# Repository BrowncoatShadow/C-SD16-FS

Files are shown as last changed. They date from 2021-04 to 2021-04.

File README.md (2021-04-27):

# Chauvet Stage Designer 16 Foot Pedal USB Macro Pad

This is a simple project to create an adapter that turns a Chauvet Stage
Designer 16 foot pedal into a USB macro foot switch.

The foot pedal is a very simple device. It has four spring-loaded pedals over
a PCB with four momentary switches. The PCB connects to a standard male DB-9
D-SUB connector. It uses pin 5 as a common line for the switches, and pins
1-4 as the signal pins for the switches.

A [DB-9 "motherboard" connector](https://www.amazon.com/gp/product/B0067DB6RU)
can be used as a simple adapter, because it breaks out the DB-9 pins to a
standard 2x5 pin IDC header; which can be easily connected to a microcontroller.

This project uses the [Adafruit Feather M0 Express](https://www.adafruit.com/product/3403)
microcontroller because it has USB HID support, intigrated pullup resisters,
and a nice proto perf board area to mount a 2x5 socket for the DB-9 adapter.

## Pinout Diagram

```
  DB-9 Male          IDC Header
                        ┌─┐
┌───────────┐      ┌────┴─┴─ ──┐
│ 1 2 3 4 5 │ ───► │ 1 2 5 8 9 │
│  6 7 8 9  │      │ 3 6 4 7 X │
└───────────┘      └───────────┘

  Connection        DB-9   Pin
  ────────────────────────────
  Ground            5      GND
  P1 (FULL ON)      4      A1
  P2 (STAND BY)     3      A2
  P3 (PATTERN UP)   2      A3
  P4 (STEP UP)      1      A4
```

## References
* [Feather Specification](https://learn.adafruit.com/adafruit-feather/feather-specification)
* [Feather M0 Express Reference](https://learn.adafruit.com/adafruit-feather-m0-basic-proto/overview)
* [Feather M0 Express CAD Model](https://github.com/adafruit/Adafruit_CAD_Parts/blob/master/3403%20Feather%20M0%20Express/3403%20Feather%20M0%20Express.stl)
* [CircuitPython Getting Started Guide](https://learn.adafruit.com/welcome-to-circuitpython)
* [Adafruit HID Library Documentation](https://circuitpython.readthedocs.io/projects/hid/en/latest/)
* [circup](https://github.com/adafruit/circup)

## Attributions
* Enclosure design is based on Heartman's [OpenScad Parametric Box](https://www.thingiverse.com/thing:1264391) [CC BY-NC 3.0 License]

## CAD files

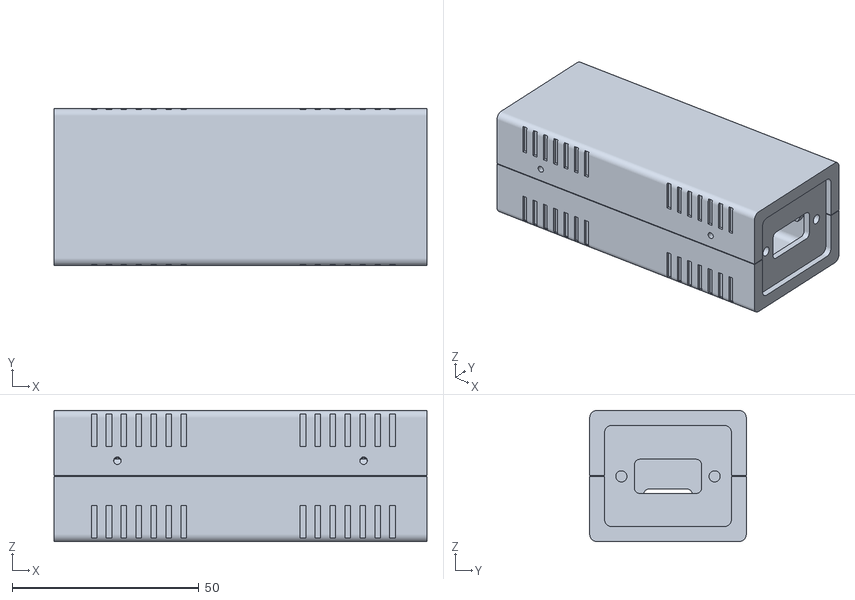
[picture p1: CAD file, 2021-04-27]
enclosure/stl/full.stl
100.0 x 42.0 x 35.2

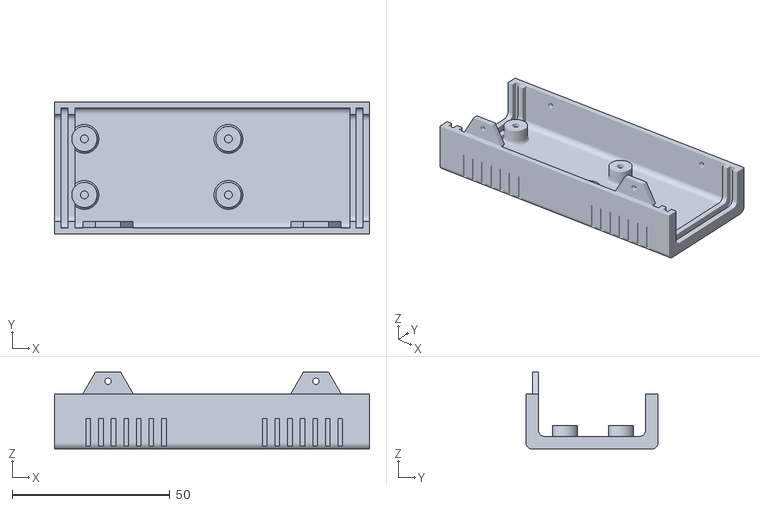
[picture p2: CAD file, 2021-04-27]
enclosure/stl/bottom_shell.stl
100.0 x 42.0 x 24.4

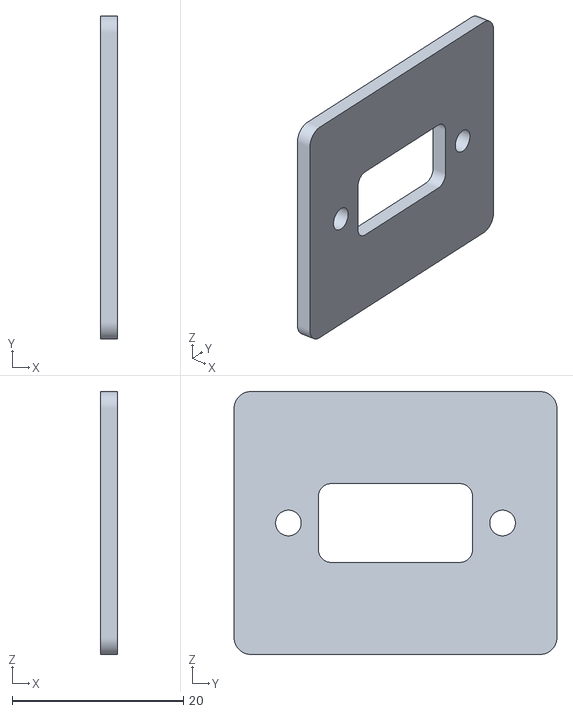
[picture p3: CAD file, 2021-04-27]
enclosure/stl/front_panel.stl
2.00 x 37.7 x 30.7

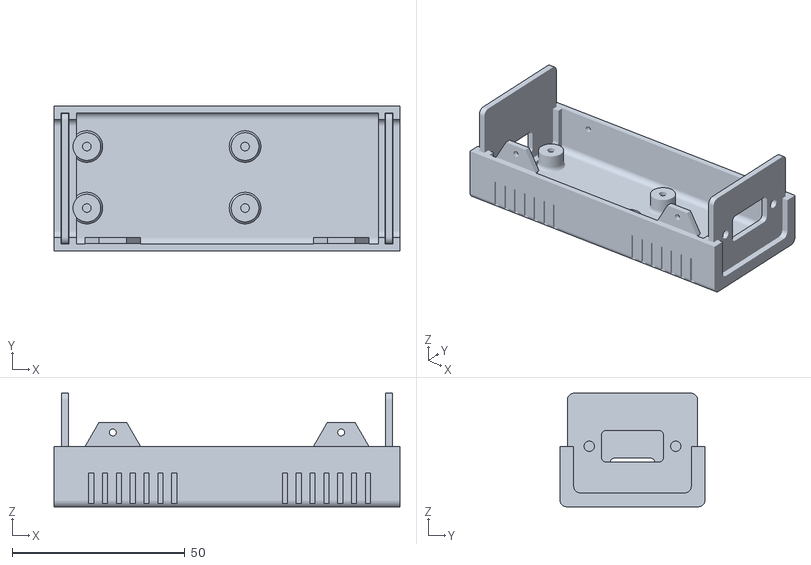
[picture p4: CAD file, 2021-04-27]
enclosure/stl/topless.stl
100.0 x 42.0 x 32.9

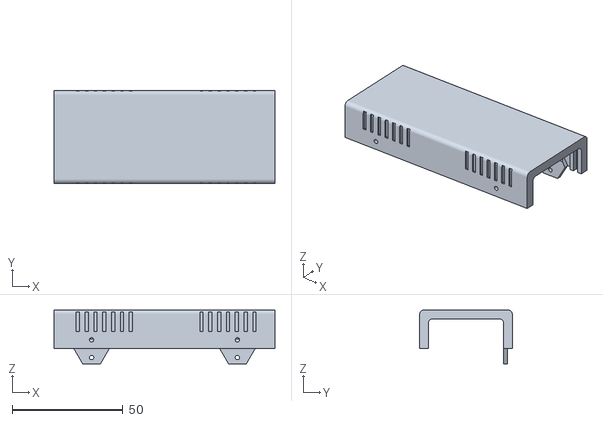
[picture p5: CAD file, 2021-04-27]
enclosure/stl/top_shell.stl
100.0 x 42.0 x 24.4

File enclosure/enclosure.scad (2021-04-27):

/* [Box Settings] */
// Length
Length = 100;
// Width
Width = 42;
// Height
Height = 35;
// Curve smoothness
Resolution = 50; // [1:100]
// Tolerance (Panel/rails gap)
Tolerance = 0.3;
// Decorations to ventilation holes
Vent = 0; // [0:No, 1:Yes]
// Decoration-Holes width (in mm)
Vent_width = 1.5;
// PCB feet (x4)
PCBFeet = 1; // [0:No, 1:Yes]
// PCB Length
PCBLength = 45.72; // 1.8" for Feather board
// PCB Width
PCBWidth = 17.78; // 0.9" for Feather board
// Hole diameter
FootHole = 2.5;
// Feet height
FootHeight = 8;

/* [Panel Holes] */
// DB-9 square hole height
DB9SquareHeight = 9.2;
// DB-9 square hole width
DB9SquareWidth = 18;
// DB-9 square hole corner radius
DB9SquareRadius = 3;
// DB-9 screw hole size
DB9ScrewSize = 3;
// DB-9 screw hole distance
DB9ScrewDistance = 25;
// USB hole width
USBWidth = 13;
// USB hole height
USBHeight = 8;
// USB hole corner radius
USBRadius = 3;

/* [Rendering] */
// Top shell
TopShell = 0; // [0:No, 1:Yes]
// Bottom shell
BottomShell = 1; // [0:No, 1:Yes]
// Front panel
FrontPanel = 1; // [0:No, 1:Yes]
// Back panel
BackPanel = 1; // [0:No, 1:Yes]


/* [Hidden] */
/*
These parameters are editable in the original SCAD design, but this
particular design uses some custom calculations that do not account
for these parameters being variable.
*/
// Wall thickness
Thick = 2; // [2:5]
// Curve diameter
Curve = 2; // [0.1:12]
// Foot diameter
FootDia = 8;

/*
These parameters were editable in the original SCAD design, but this design
auto calculates them.
*/
// Low left corner X position
PCBPosX = 0.5-(2*Thick);
// Low left corner Y position
PCBPosY = ((Width-(Thick*2+Curve*2+Tolerance*2)*0.5) - PCBWidth - (Thick+9) - (FootDia)) / 2;

/*
These parameters were hidden in the original design.
*/
// Shell color
ShellColor = "Orange";
// Panel color
PanelColor = "OrangeRed";
// Thick X 2 - making decorations thicker if it is a vent to make sure they go through shell
Dec_Thick = Vent ? Thick*2 : Thick;
// Depth decoration
Dec_size = Vent ? Thick*2 : 0.8;

/*
These parameters are custom to this design for calculating panel hole placement.
*/
DB9ScrewOffsetX = DB9ScrewSize / 2;
DB9ScrewOffsetY = DB9SquareHeight / 2;
DB9SquareOffsetX = ((DB9ScrewDistance + DB9ScrewSize) - DB9SquareWidth) / 2;
// DB-9 panel-mount hole
DB9PanelX = ((Width-(Thick*2+Curve*2+Tolerance*2)*0.5) - (DB9ScrewDistance+DB9ScrewSize)) / 2;
DB9PanelY = ((Height-(Thick*2+Curve*2+Tolerance*2)*0.5) - DB9SquareHeight) / 2;
// USB socket hole
USBPanelX = ((Width-(Thick*2+Curve*2+Tolerance*2)*0.5) - USBWidth) / 2;
USBPanelY = (FootHeight - (USBHeight/2));

module RoundBox($a=Length, $b=Width, $c=Height)
{
    $fn=Resolution;
    translate([0,Curve,Curve])
    {
        minkowski()
        {
            cube([$a-(Length/2),$b-(2*Curve),$c-(2*Curve)], center=false);
            rotate([0,90,0])
            {
                cylinder(r=Curve,h=Length/2, center=false);
            }
        }
    }
}

module Shell()
{
    Thick = Thick*2;
    difference()
    {
        // Side decorations
        difference()
        {
            union()
            {
                // Substraction Curveed box
                difference()
                {
                    // Median cube slicer
                    difference()
                    {
                        union()
                        {
                            // Shell
                            difference()
                            {
                                RoundBox();
                                translate([Thick/2,Thick/2,Thick/2])
                                {
                                    RoundBox($a=Length-Thick, $b=Width-Thick, $c=Height-Thick);
                                }
                            }

                            // Inside rails
                            difference()
                            {
                                translate([Thick+Tolerance,Thick/2,Thick/2])
                                {
                                    RoundBox($a=Length-((2*Thick)+(2*Tolerance)), $b=Width-Thick, $c=Height-(Thick*2));
                                }
                                translate([((Thick+Tolerance/2)*1.55),Thick/2,Thick/2+0.1]) // +0.1 added to avoid the artefact
                                {
                                    RoundBox($a=Length-((Thick*3)+2*Tolerance), $b=Width-Thick, $c=Height-Thick);
                                }
                            }
                        }

                        // Internal cube to subtract
                        translate([-Thick,-Thick,Height/2])
                        {
                            cube([Length+100, Width+100, Height], center=false);
                        }
                    }

                    // Core subtraction for ends
                    translate([-Thick/2,Thick,Thick])
                    {
                        RoundBox($a=Length+Thick, $b=Width-Thick*2, $c=Height-Thick);
                    }
                }


                // Screw tab legs
                difference()
                {
                    union()
                    {
                        translate([3*Thick +5,Thick,Height/2])
                        {
                            rotate([90,0,0])
                            {
                                $fn=6;
                                cylinder(d=16,Thick/2);
                            }
                        }

                       translate([Length-((3*Thick)+5),Thick,Height/2])
                       {
                            rotate([90,0,0])
                            {
                                $fn=6;
                                cylinder(d=16,Thick/2);
                            }
                        }

                    }

                    translate([4,Thick+Curve,Height/2-57])
                    {
                        rotate([45,0,0])
                        {
                            cube([Length,40,40]);
                        }
                    }
                    translate([0,-(Thick*1.46),Height/2])
                    {
                        cube([Length,Thick*2,10]);
                    }
                }
            }

            // Outside decorations
            union()
            {

                for(i=[0:Thick:Length/4])
                {

                        // Ventilation holes
                        translate([10+i,-Dec_Thick+Dec_size,1])
                        {
                            cube([Vent_width,Dec_Thick,Height/4]);
                        }
                        translate([(Length-10) - i,-Dec_Thick+Dec_size,1])
                        {
                            cube([Vent_width,Dec_Thick,Height/4]);
                        }
                        translate([(Length-10) - i,Width-Dec_size,1])
                        {
                            cube([Vent_width,Dec_Thick,Height/4]);
                        }
                        translate([10+i,Width-Dec_size,1])
                        {
                            cube([Vent_width,Dec_Thick,Height/4]);
                        }


                }

            }
        }

        // Screw holes
        union()
        {
            $fn=50;
            translate([3*Thick+5,20,Height/2+4]){
                rotate([90,0,0]){
                cylinder(d=2,20);
                }
            }
            translate([Length-((3*Thick)+5),20,Height/2+4]){
                rotate([90,0,0]){
                cylinder(d=2,20);
                }
            }
            translate([3*Thick+5,Width+5,Height/2-4]){
                rotate([90,0,0]){
                cylinder(d=2,20);
                }
            }
            translate([Length-((3*Thick)+5),Width+5,Height/2-4]){
                rotate([90,0,0]){
                cylinder(d=2,20);
                }
            }
        }

    }
}

// Single PCB mounting foot with curved base
module foot(FootDia,FootHole,FootHeight)
{
    Curve=2;
    color(ShellColor)
    translate([0,0,Curve-1.5])
    difference()
    {
        difference()
        {
            cylinder(d=FootDia+Curve,FootHeight-Thick, $fn=100);
            rotate_extrude($fn=100)
            {
                translate([(FootDia+Curve*2)/2,Curve,0])
                {
                    minkowski()
                    {
                        square(10);
                        circle(Curve, $fn=100);
                    }
                }
            }
        }
        cylinder(d=FootHole,FootHeight+1, $fn=100);
    }
}

// All PCB mounting feet and visual PCB reference
module Feet(){

    // Render a PCB that is not exported
    translate([3*Thick+4.5,Thick+7.5,FootHeight+(Thick/2)-1.5])
    {
        %import("lib/3403 Feather M0 Express.stl");
    }
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

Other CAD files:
enclosure/stl/back_pannel.stl

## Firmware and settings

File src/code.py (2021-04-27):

import time
import board
import digitalio
import usb_hid
from adafruit_hid.keyboard import Keyboard
from adafruit_hid.keycode import Keycode

key_pins = [
    board.A1, # FULL ON
    board.A2, # STAND BY
    board.A3, # PATTERN UP
    board.A4  # STEP UP
]

key_binds = [
    # Unclutched
    [Keycode.F13],
    [Keycode.F14],
    [Keycode.F15],
    # Clutched
    [Keycode.F16],
    [Keycode.F17],
    [Keycode.F18],
]

# Initialize keyboard
time.sleep(1)
keyboard = Keyboard(usb_hid.devices)

# Setup all input pins
key_pin_array = []
for pin in key_pins:
    key_pin = digitalio.DigitalInOut(pin)
    key_pin.direction = digitalio.Direction.INPUT
    key_pin.pull = digitalio.Pull.UP
    key_pin_array.append(key_pin)

# Setup LED
led = digitalio.DigitalInOut(board.D13)
led.direction = digitalio.Direction.OUTPUT

# First pedal is clutch
clutch = key_pin_array.pop(0)

while True:
    # Check for clutch each loop
    clutched = False
    if not clutch.value:
        clutched = True

    # Check each other pedal
    for key_pin in key_pin_array:
        if not key_pin.value:
            led.value = True
            i = key_pin_array.index(key_pin)

            # Get clutched or unclutched key binds
            key = key_binds[i+3] if clutched else key_binds[i]
            # Send keys; asterisk deconstructs array into seperate arguments
            keyboard.press(*key)

            # Wait for the pedal to be released
            while not key_pin.value:
                pass

            # Release all keys
            keyboard.release_all()
            led.value = False
    time.sleep(0.01)
